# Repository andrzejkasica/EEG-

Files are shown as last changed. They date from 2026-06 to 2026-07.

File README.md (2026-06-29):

# EEG-
EEG hardware project. Device based on STM32

**Hardware**
 - STM32F446RE
 - BLE module
 - USB Type-C connector + USB Isolator
 - AFE:
   ADS1299 (TI) 8 chan
   ADS1298 (TI) 8 chan
   AD7771 (Analog Devices) 8 chan
   INA114 - single channel
 - LDO
 - Electrodes (to be chosen)
 - Electrode cables
 - Battery / Acu 

**Software & Tools**
  - STM32CubeIDE
  - eDesignSuite - ST's online design tools: st.com/edesign
  - MNE-Python
  - BESA Simulator
  - Python

**Electrodes**
- Wet (Ag/AgCl)	Best signal quality, low impedance	Requires gel, preparation time
- Dry	No prep, comfortable	Higher impedance, more noise
- Semi-dry	Balance of both	Limited availability

**Reference Open source projects**
  - https://pieeg.com/microbci/
    STM32 shield for EEG/EMG/ECG,
    8 channels, NUCLEO-WB55 compatible, Python software
  - https://github.com/pieeg-club/ironbci
    Wearable BCI with ADS1299 + STM32 
    BLE, mobile SDK, 3D printable headset designs
  - https://www.crowdsupply.com/neuroidss/freeeeg32
    32-channel research-grade EEG
    STM32H7, 4x AD7771 ADCs, high-quality acquisition
  - https://www.hackster.io/mustafamelihcan/open-source-diy-eeg-brainwaves-on-a-custom-pcb-99146e
    Single-channel custom PCB EEG

**Diagram**
┌─────────────┐    ┌──────────────┐    ┌─────────────┐    ┌──────────────┐
│  Electrodes │───▶│  AFE         │───▶│  STM32 MCU  │───▶│  Output      │
│  (Scalp)    │    │  (ADS1299)   │    │  (F4/H7)    │    │  (USB/BLE)   │
└─────────────┘    └──────────────┘    └─────────────┘    └──────────────┘
                         │                    │
                   ┌─────┴─────┐        ┌─────┴─────┐
                   │ SPI Bus   │        │ DSP/Filter│
                   │ (16 MHz)  │        │ Processing│
                   └───────────┘        └───────────┘

**Links**
https://www.ti.com/product/ADS1299
https://www.ti.com/lit/an/sbaa188a/sbaa188a.pdf
https://www.st.com/content/st_com/en/support/learning/stm32-education.html
https://www.instructables.com/Measure-EEG-With-STM32-Nucleo-Board/

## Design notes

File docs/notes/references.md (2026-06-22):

## STM32 EEG – References

### Repos
- https://github.com/Ildaron/ironbci
- https://github.com/Absolute0K/OpenLD-Hardware
- https://github.com/unaldevelopment/EEG-Symbols-and-Footprints

### Forums & articles
- https://e2e.ti.com/support/data-converters/f/data-converters-forum/432593/stm32-and-ads1299-eeg-fe-daughter-card-spi-communication
- https://hackaday.io/project/13285-openld-lucid-dreaming-research-platform/log/45480-firmware-for-openld-stm32f4-w-ads1299
- https://openbci.com/forum/index.php?p=%2Fdiscussion%2F81%2Fstm32-diy-board-with-ads1299-sparkyeeg

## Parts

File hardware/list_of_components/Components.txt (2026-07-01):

Components List - EEG Project

Source note: LTSC or local supplier. Prioritise LCSC/Mouser.
TI reference: ADS1299EEG-FE EVM (SLAU443B, Figure 60 power schematic + Table 10 BOM)

=============================================================================
ANALOG FRONT END
=============================================================================
U_AFE    ADS1299CPAG    TI    ADS1299, 8-ch 24-bit EEG AFE, TQFP-64
         DVDD: 1.8V-3.6V | AVDD/AVSS: unipolar 5V or bipolar ±2.5V
         SPI interface, internal reference (4.5V) or external

=============================================================================
MICROCONTROLLER
=============================================================================
U_MCU    STM32F446RET6    ST    ARM Cortex-M4, 180MHz, LQFP-64
         3.3V supply | FPU | USB OTG FS | SPI | USART

=============================================================================
POWER SUPPLY - ANALOG (following TI EVM reference, Figure 60 SLAU443B)
=============================================================================
Design: Bipolar ±2.5V analog supply (AVDD=+2.5V, AVSS=-2.5V)
Input: 5V_ISO (isolated 5V from USB isolator or battery)

--- +2.5V AVDD rail ---
U_AVDD   TPS73225DBVT    TI    LDO +2.5V 250mA, SOT-23-5
         IN: 5V_ISO, OUT: +2.5V AVDD
         Same as TI EVM U9
         Datasheet: https://www.ti.com/product/TPS73225

--- -5V intermediate (charge pump) ---
U_CP     TPS60403DBVT    TI    Unregulated charge pump inverter, SOT-23-5
         IN: 5V_ISO, OUT: ~-5V (unregulated, feeds negative LDO)
         Same as TI EVM U6
         Datasheet: https://www.ti.com/product/TPS60403

--- -2.5V AVSS rail ---
U_AVSS   TPS72325DBVT    TI    Negative LDO -2.5V 200mA, SOT-23-5
         IN: ~-5V (from TPS60403), OUT: -2.5V AVSS
         Same as TI EVM U8
         Datasheet: https://www.ti.com/product/TPS72325

=============================================================================
POWER SUPPLY - DIGITAL
=============================================================================
--- +3.3V DVDD rail ---
U_DVDD   TLV757P33DRVR    TI    LDO +3.3V 500mA, WSON-6 (2x2mm), 28uVrms
         IN: 5V_ISO, OUT: +3.3V DVDD (STM32 VDD + ADS1299 DVDD)
         Not in TI EVM (supplied externally from MMB0 host)
         Datasheet: https://www.ti.com/product/TLV757P
         NOTE: If noise budget allows, LP5907MFX-3.3 (250mA, 6.5uVrms) is
               lower noise but may be tight for STM32 USB active mode (~200mA)

=============================================================================
POWER SUPPLY - INDUCTORS (same values as TI EVM, TDK MLZ2012A3R3WT)
=============================================================================
L1       3.3uH    Multilayer    0805    TPS60403 input EMI filter
L2       3.3uH    Multilayer    0805    TPS60403 output EMI filter
L3       3.3uH    Multilayer    0805    TPS73225 (+2.5V) output filter
L4       3.3uH    Multilayer    0805    TPS72325 (-2.5V) output filter

=============================================================================
POWER SUPPLY - DECOUPLING CAPACITORS
=============================================================================
Following TI EVM values (Table 10 / Figure 60):

5V rail input:
  C_5V_1   10uF   X5R   0805   (x2, input bulk for TPS60403 + TPS73225)
  C_5V_2    1uF   X7R   0603   (x2, input bypass)

TPS60403 charge pump cap:
  C_CP      1uF   X7R   0603   (charge pump capacitor, between C1+/C1-)

+2.5V AVDD output (TPS73225):
  C_AVD_1   2.2uF  X5R  0603
  C_AVD_2  10uF   X5R   0805
  C_AVD_3  10uF   X5R   0805

-5V intermediate output (TPS60403):
  C_N5_1   10uF   X5R   0805
  C_N5_2    1uF   X7R   0603

-2.5V AVSS output (TPS72325):
  C_AVS_1   2.2uF  X5R  0603
  C_AVS_2  10uF   X5R   0805
  C_AVS_3  10uF   X5R   0805
  C_AVS_4   0.01uF X7R  0603   (high-freq bypass)

+3.3V DVDD output (TLV757P):
  C_DV_1   10uF   X5R   0805
  C_DV_2    1uF   X7R   0603
  C_DV_3    0.1uF X7R   0603

ADS1299 per-pin DVDD bypass:
  C_AFE_D   0.1uF X7R   0603   (x4, one per DVDD pin on ADS1299)

ADS1299 per-pin AVDD bypass:
  C_AFE_A   0.1uF X7R   0603   (x2, AVDD and AVSS pins)
  C_AFE_A2  1uF   X5R   0603   (x2, AVDD and AVSS bulk)

STM32 VDD bypass (per VDD pin):
  C_MCU     0.1uF X7R   0603   (x4, one per VDD/VDDA pin)
  C_MCU2    1uF   X5R   0603   (x2, VDD and VDDA bulk)
  C_MCU3   10uF   X5R   0805   (x1, main VDD bulk)

=============================================================================
USB / ISOLATION
=============================================================================
U_ISO    ADUM3160BRWZ    ADI    USB 2.0 full-speed isolator, SOIC-16-W
         Isolates USB data lines (D+/D-). Does NOT isolate power.
         Patient side powered from battery or isolated DC-DC.
         Datasheet: https://www.analog.com/en/products/adum3160.html

         NOTE: ADUM3160 requires separate isolated 5V on device side.
         If USB-powered (no battery): add an isolated DC-DC converter
         (e.g. TI DCH010505S or RECOM R-78E5.0-0.5) on the device side
         to generate 5V_ISO from 5V_USB.

U_ESD    USBLC6-2SC6    ST    USB ESD protection, SOT-23-6
         Place on USB-C data lines, PC side of isolator

CON_USB  USB-C receptacle    GCT USB4135-GF-A or Amphenol 12401610E4#2A
         USB 2.0 only (no CC1/CC2 PD negotiation needed for 5V/500mA)
         Add 5.1kOhm resistors on CC1 and CC2 to GND (device mode)

=============================================================================
OSCILLATOR (for ADS1299 external clock option)
=============================================================================
OSC1     FXO-HC735-2.048    Fox    2.048MHz HCMOS SMD oscillator, 3.3V
         Same as TI EVM OSC1
         Used if ADS1299 CLKSEL=1 (external clock mode)
         Alternative: SiT8002AC-34-18E-2.048 (1.8V version if DVDD=1.8V)

=============================================================================
DEBUG / PROGRAMMING
=============================================================================
CON_SWD  1x5 2.54mm header    SWD debug connector (SWDIO/SWDCK/NRST/VDD/GND)
CON_UART 1x4 2.54mm header    USART3 TX/RX debug UART (from STM32 PB10/PC5)

=============================================================================
TEST POINTS (recommended, following TI EVM practice)
=============================================================================
TP_5V    +5V_ISO rail
TP_3V3   +3.3V DVDD
TP_AVDD  +2.5V AVDD
TP_AVSS  -2.5V AVSS
TP_N5V   ~-5V intermediate
TP_GND   Analog GND
TP_DGND  Digital GND

=============================================================================
NOTES
=============================================================================
- AGND and DGND: connect at single star point near ADS1299 decoupling cap.
  Keep analog and digital ground pours separate on PCB.
- 5V_ISO: completely isolated from USB VBUS / PC ground.
  If battery powered: 5V_ISO = battery regulated output.
  If USB powered: 5V_ISO = output of isolated DC-DC converter.
- ADS1299 VREF: use internal reference (2.4V internal = 4.5V swing for 24-bit).
  External reference (REF3240, 4.096V) optional for better accuracy.

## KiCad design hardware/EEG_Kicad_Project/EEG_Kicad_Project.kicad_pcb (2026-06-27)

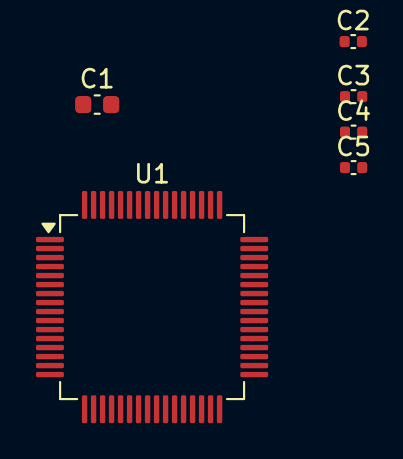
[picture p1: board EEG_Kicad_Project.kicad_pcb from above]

Board: 2 copper layers, 6 parts (0 on the bottom side), 2 nets, no tracks yet.

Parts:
C1: 1u; C_0603_1608Metric
C2, C3, C4, C5: 100n; C_0402_1005Metric
U1: STM32F446RETx; LQFP-64_10x10mm_P0.5mm

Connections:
+3V3: C1.1, C2.1, C3.1, C4.1, C5.1, U1.19 (VDD), U1.32 (VDD), U1.48 (VDD), U1.64 (VDD)
GND: C1.2, C2.2, C3.2, C4.2, C5.2, U1.18 (VSS), U1.31 (VSS), U1.47 (VSS), U1.63 (VSS)

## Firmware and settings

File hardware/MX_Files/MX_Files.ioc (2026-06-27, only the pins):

Mcu.UserName=STM32F446RETx
PA11.Signal=USB_OTG_FS_DM
PA12.Signal=USB_OTG_FS_DP
PA5.Signal=SPI1_SCK
PA6.Signal=SPI1_MISO
PA7.Signal=SPI1_MOSI
PB10.Signal=USART3_TX
PB3.GPIO_Label=LED_2
PB3.Signal=GPIO_Output
PB4.GPIO_Label=LED_1
PB4.Signal=GPIO_Output
PC5.Signal=USART3_RX
PH0-OSC_IN.Signal=RCC_OSC_IN
PH1-OSC_OUT.Signal=RCC_OSC_OUT

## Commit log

2026-01-05 Enhance README with AFE details and additional resources
    Added detailed information about AFE components, software tools, electrodes, and relevant links.
2026-05-04 added stm32IDE files to gitignore for hardware
2026-06-21 add recommended project structure and root gitignore
    - add hardware/schematic, hardware/pcb, hardware/bom directories
    - add software/acquisition, software/processing, software/cursor directories
    - add root .gitignore covering OS, Python, and KiCad artifacts
    - add initial STM32CubeIDE project skeleton for STM32F446RE
2026-06-22 First sketch of STM32 configuration, adding ioc file
2026-06-24 add Kicad porject with gitignore
    [EEG Kicad Project.kicad_pcb, EEG Kicad Project.kicad_sch]
2026-06-24 Added uC and started organizing schematic into sections: Power, uC, Analog
    [EEG Kicad Project.kicad_pcb, EEG Kicad Project.kicad_sch]
2026-06-27 Added datasheet, modify STM32 pinout in MX, added labels on schematic, added STM32 hierarch sheet
    [EEG Kicad Project.kicad_pcb, EEG Kicad Project.kicad_sch, stm32.kicad_sch]
2026-06-27 Deleted folders: EEG kicad Project, PCB, Schematic
2026-06-27 rename spaces from Catalogs and files
    [EEG_Kicad_Project.kicad_pcb, EEG_Kicad_Project.kicad_sch, stm32.kicad_sch]
2026-06-28 Added ADS1299, hierarchical sheets for: power, usb, analog, stm
    [analog_in.kicad_sch, power.kicad_sch, stm32.kicad_sch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]
2026-06-29 Readme change, add -5V, some organizational changes
    [EEG_Kicad_Project.kicad_sch, analog_in.kicad_sch, power.kicad_sch]
2026-07-01 added power LDO IC's started routing
    [power.kicad_sch]
2026-07-10 added 3V3 /-2V5 wiring on schematic
2026-10-23 Add USB galvanic isolation barrier for patient safety
    Adds a USB-C receptacle -> ESD protection -> ADuM3160 isolator ->
    isolated TMU3-0511 DC-DC chain, separating the STM32/ADS1299/analog
    supply (now fully isolated) from the non-isolated USB-connector side.
    Closes the previously-floating USB_OTG_FS_DP/DM pins on the STM32,
    adds CC1/CC2 pulldowns and VBUS decoupling on the new receptacle, and
    fixes ADuM3160 VBUS2 tie per datasheet. Verified via kicad-happy: no
    ERC regressions, isolation barrier confirmed intact (no net bridges
    GND_PRI/+5V_PRI with the isolated GNDA/+5V/+3V3 domain).
2026-10-23 Add EEG board completion plan
    Step-by-step plan from current schematic state to an ordered/assembled
    board: isolation barrier, remaining schematic gaps, BOM sourcing, PCB
    layout, fab prep, and bring-up testing.
